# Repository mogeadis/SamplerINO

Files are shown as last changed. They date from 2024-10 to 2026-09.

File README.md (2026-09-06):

# SamplerINO 🔲

## Table of Contents

- [Description](#description)
    - [Project](#project)
    - [Repository](#repository)
    - [Technical Details](#technical-details)
- [Gallery](#gallery)
    - [Circuit Diagram](#circuit-diagram)
    - [3D Models](#3d-models)
    - [Hardware Assembly](#hardware-assembly)
    - [User Interface](#user-interface)
- [License](#license)

## Description

### Project
**SamplerINO** utilizes an *ATmega32U4* microcontroller and two *CAP1188* 8-channel capacitive touch sensor modules to assemble a USB MIDI controller featuring 16 touch-sensitive pads. The prototype circuit board is housed inside a custom-designed 3D printed enclosure, which facilitates the installation of the pads, as well as an LED indicator and a power switch. You can watch a video demonstration of this hardware MIDI controller and its dedicated software sampler at the following [link](https://youtu.be/IzE63Gio5Jo).

### Repository
The code in this repository is organized into several directories, with the source (`.cpp`) and header (`.h`) files of the controller located in the [*src*](src) and [*include*](include) directories, respectively. The *Max* patch implementing the user interface of the accompanying sampler, along with a collection of drum samples gathered from various royalty-free web sources, are contained in the [*max*](max) directory. Lastly, the 3D model (`.stl`) files are located in the [*3d*](3d) directory, while the [*img*](img) directory contains all images displayed in the present documentation.

### Technical Details
This project was developed using `Max 8.1.11` and *Visual Studio Code* on `Windows 10`, with the *PlatformIO* extension employed to upload the code to the *ATmega32U4* microcontroller embedded in an *Arduino*-compatible *Pro Micro* board. The controller pads were made by cutting 4×4cm pieces from a 0.5mm thick copper sheet, while the enclosure screw holes were designed for M2 threaded heat inserts. Lastly, a common anode RGB LED was used for the LED indicator, connected to 1KΩ resistors to prevent excessive current.

## Gallery

### Circuit Diagram
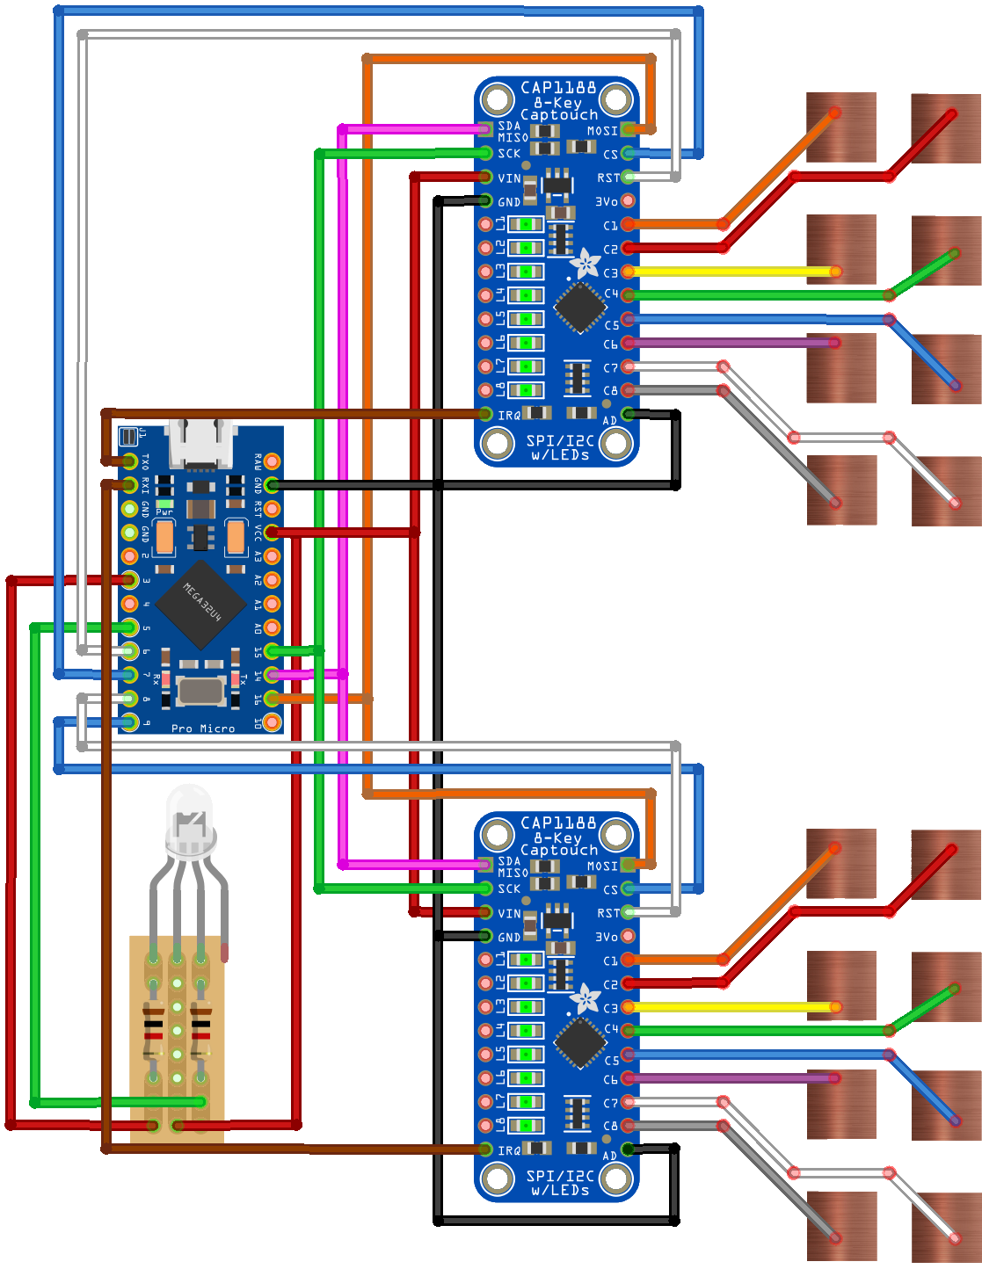
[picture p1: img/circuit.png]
Circuit Diagram


### 3D Models
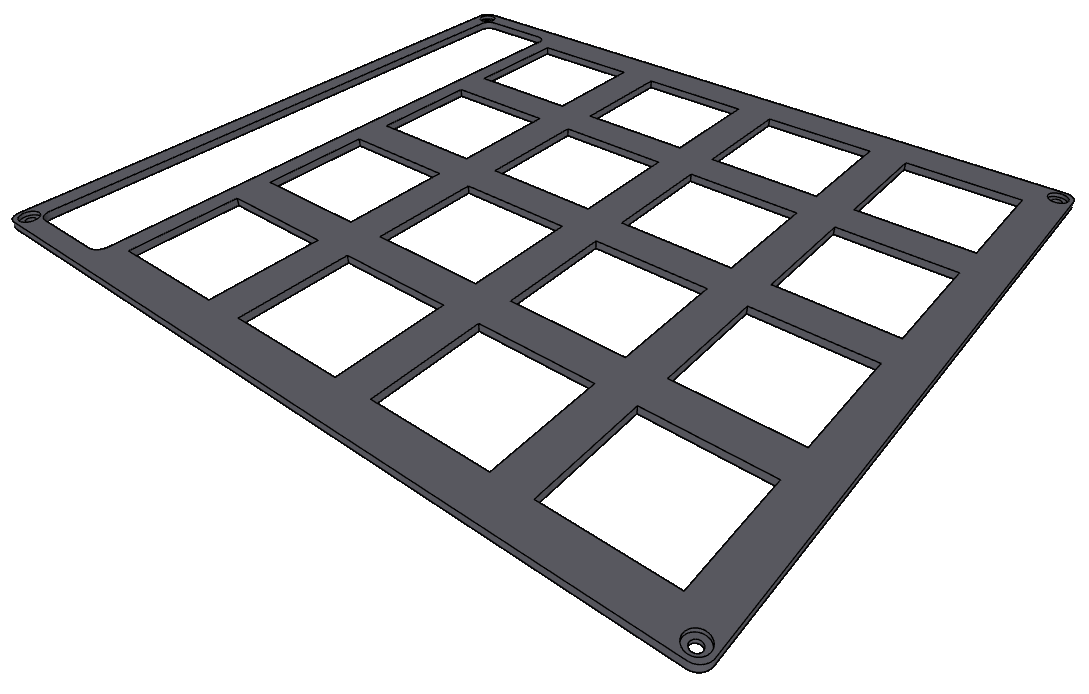
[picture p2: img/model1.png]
3D Model (Cover)

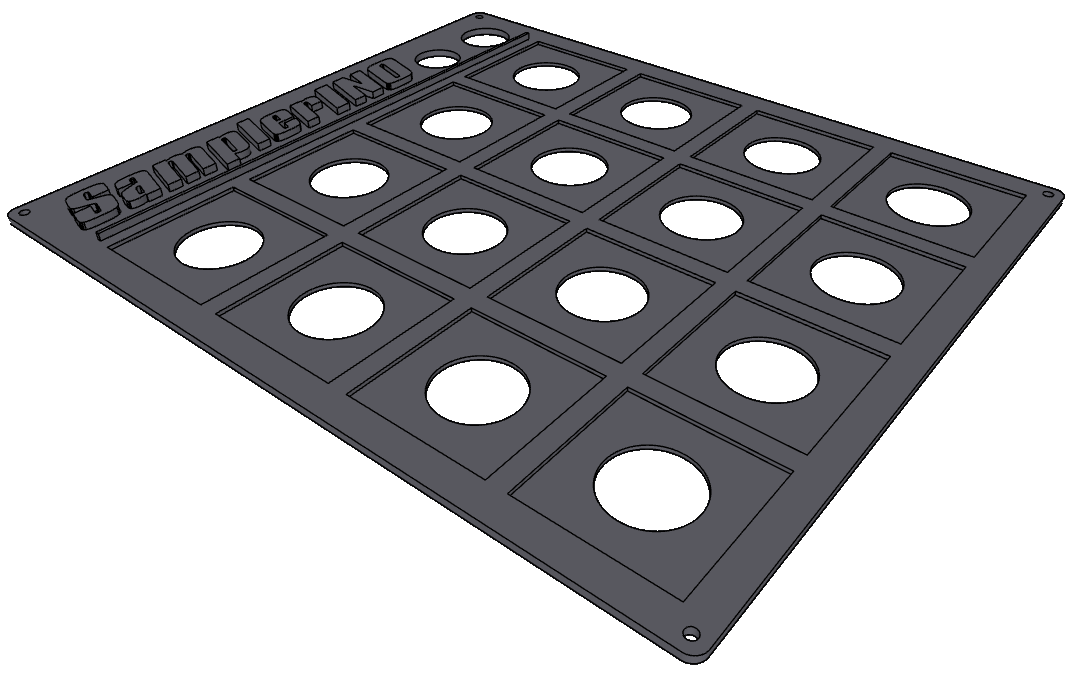
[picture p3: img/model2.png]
3D Model (Lid)

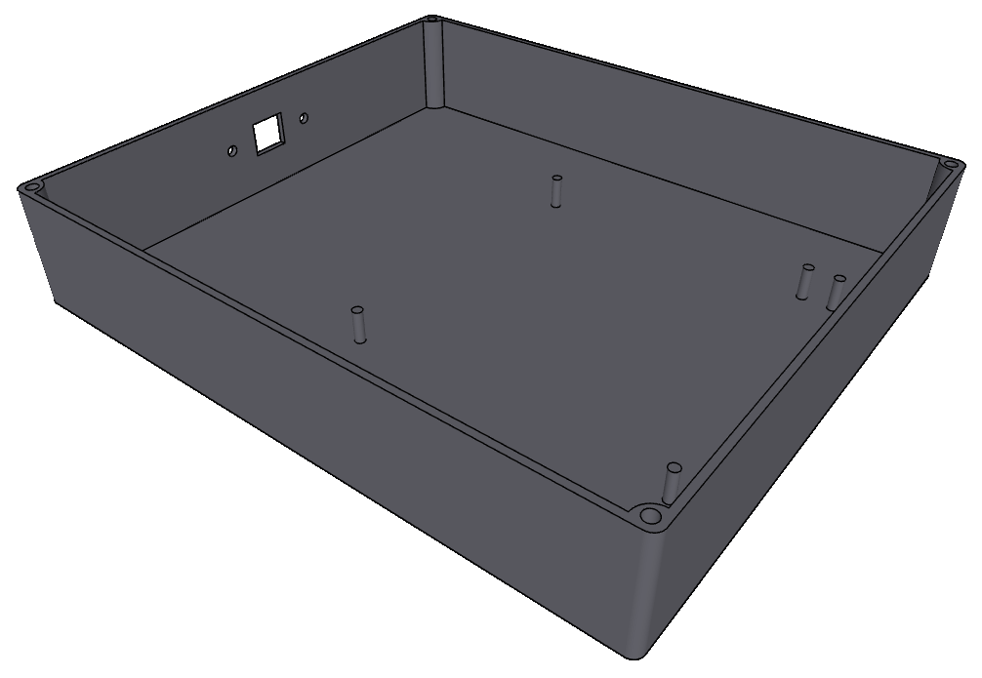
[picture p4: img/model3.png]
3D Model (Body)


### Hardware Assembly
Controller (#1)
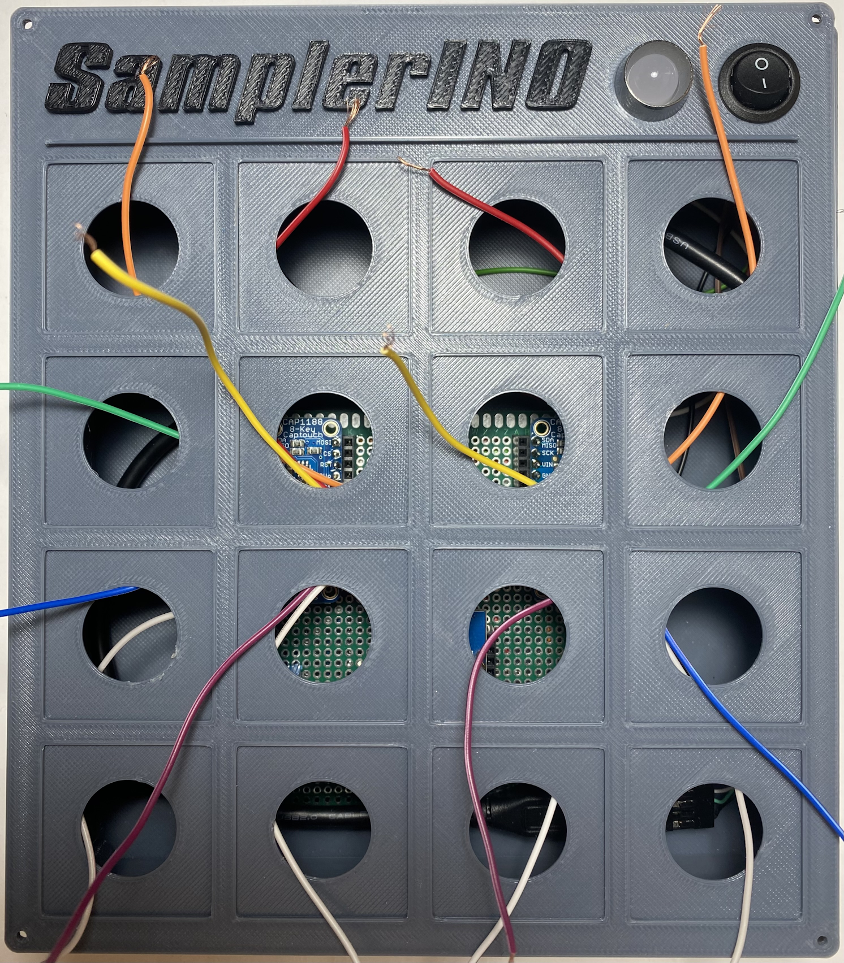
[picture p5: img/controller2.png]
Controller (#2)

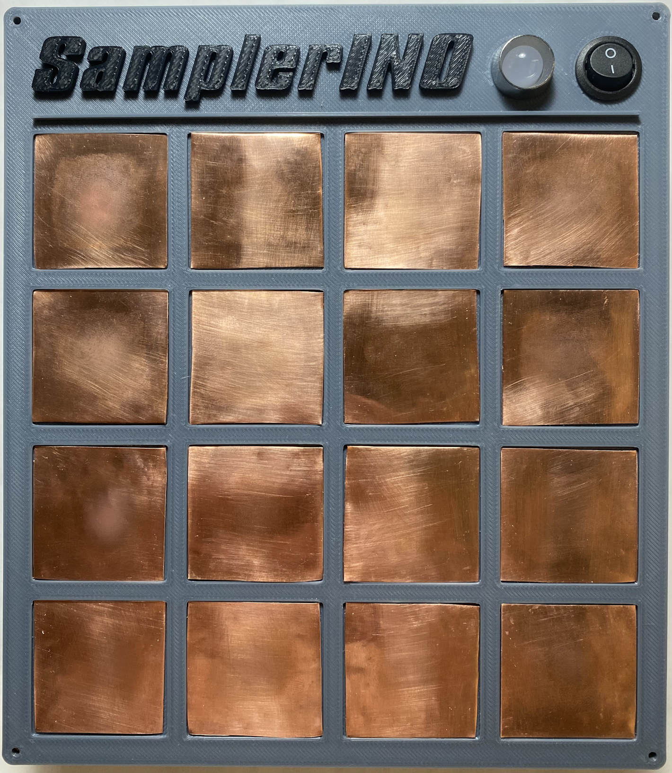
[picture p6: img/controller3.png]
Controller (#3)

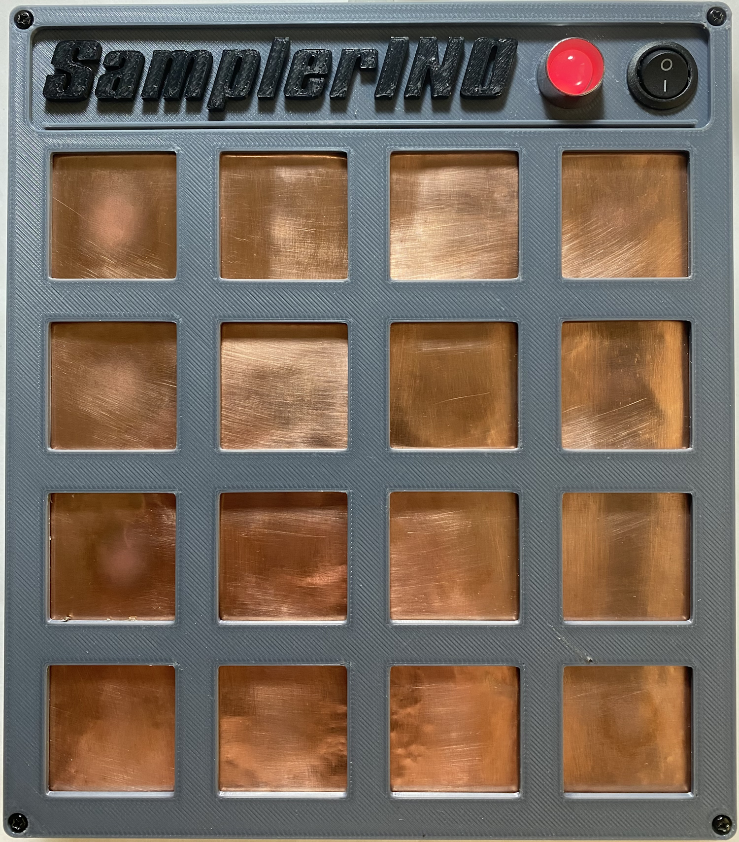
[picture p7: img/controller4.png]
Controller (#4)


### User Interface
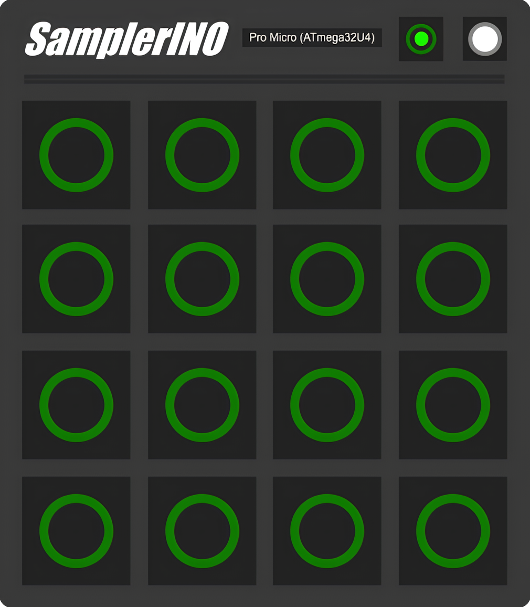
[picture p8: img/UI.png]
User Interface


## License

*SamplerINO* © *2024* by *Alexandros Iliadis* is licensed under the [GNU General Public License v3.0](https://choosealicense.com/licenses/gpl-3.0/).

Permissions of this strong copyleft license are conditioned on making available complete source code of licensed works and modifications, which include larger works using a licensed work, under the same license. Copyright and license notices must be preserved. Contributors provide an express grant of patent rights.

See the [`LICENSE.md`](LICENSE.md) file for more details.

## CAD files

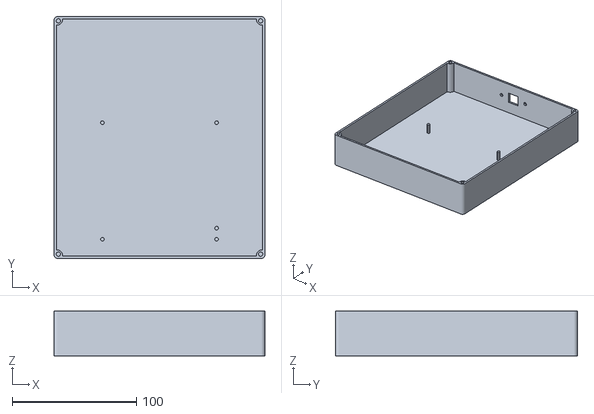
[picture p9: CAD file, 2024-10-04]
3d/model3.stl
170.0 x 195.0 x 36.0

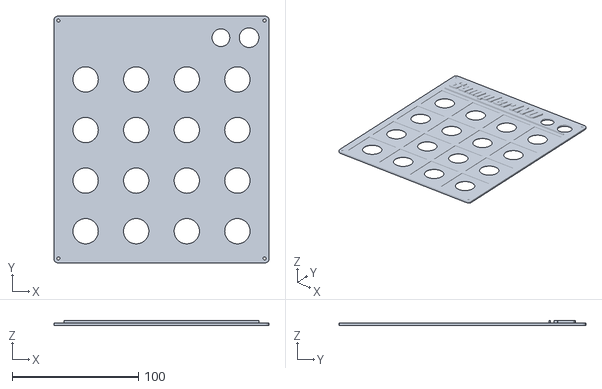
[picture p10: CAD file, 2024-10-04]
3d/model1.stl
170.0 x 195.0 x 4.00

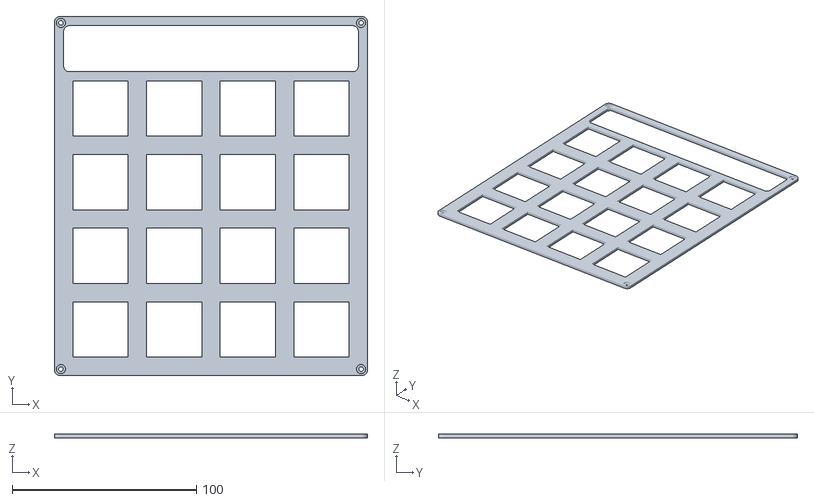
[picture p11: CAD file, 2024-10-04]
3d/model2.stl
170.0 x 195.0 x 2.00

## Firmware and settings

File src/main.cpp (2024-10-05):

/**************************************************************************************************
Filename: main.cpp

Description: This source file sets up the core functionality of the controller

Author: Alexandros Iliadis
Project: SamplerINO
Date: May 2024
**************************************************************************************************/

#include <Arduino.h>
#include "utilities.h"
#include "sensors.h"
#include "midi.h"

void setup()
{
	setupSerial();
	setupLED();
	setupModules();
}

void loop()
{
	if(interrupt)
	{
		registerNotes();
		sendData();
		interrupt = false;
	}
	controlLED();
}

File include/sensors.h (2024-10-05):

/**************************************************************************************************
Filename: sensors.h

Description: This header file sets up the touch sensors of the controller

Author: Alexandros Iliadis
Project: SamplerINO
Date: May 2024
**************************************************************************************************/

#ifndef SENSORS
#define SENSORS

// Include Libraries
#include <Arduino.h>
#include <Adafruit_CAP1188.h>

// Define Macros
#define NUM_OF_MODULES 2
#define SENSORS_PER_MODULE 8
#define NUM_OF_SENSORS NUM_OF_MODULES*SENSORS_PER_MODULE
#define MAIN_REGISTER 0x00
#define SENSORS_REGISTER 0x03
#define STANDBY_REGISTER 0x40
#define STANDBY_VALUE 0b11111111
#define REPEAT_RATE_REGISTER 0x28
#define REPEAT_RATE_VALUE 0b00000000
#define CALIBRATION_REGISTER 0x26
#define CALIBRATION_VALUE 0b11111111
#define RECALIBRATION_REGISTER 0x2F
#define RECALIBRATION_VALUE 0b10011111
#define CYCLE_REGISTER 0x24
#define CYCLE_VALUE 0b0001100
#define STANDBY_CYCLE_REGISTER 0x41
#define STANDBY_CYCLE_VALUE 0b0001100
#define SENSITIVITY_REGISTER 0x1F
#define SENSITIVITY_VALUE 0b1101111
#define STANDBY_SENSITIVITY_REGISTER 0x42
#define STANDBY_SENSITIVITY_VALUE 0b110

// Declare Variables
extern Adafruit_CAP1188 modules[NUM_OF_MODULES];
extern const byte cs_pins[NUM_OF_MODULES];
extern const byte rst_pins[NUM_OF_MODULES];
extern const byte irq_pins[NUM_OF_MODULES];
extern bool sensor_state[NUM_OF_SENSORS];
extern byte active_sensors;
extern volatile bool interrupt;

// Declare Functions
void setupModules();
void handleInterrupt();

#endif

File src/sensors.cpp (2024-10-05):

/**************************************************************************************************
Filename: sensors.cpp

Description: This source file defines the components declared in the corresponding header file

Author: Alexandros Iliadis
Project: SamplerINO
Date: May 2024
**************************************************************************************************/

#include "sensors.h"

// Define Variables
Adafruit_CAP1188 modules[NUM_OF_MODULES];
const byte cs_pins[NUM_OF_MODULES] = {9,7};
const byte rst_pins[NUM_OF_MODULES] = {8,6};
extern const byte irq_pins[NUM_OF_MODULES] = {1,0};
bool sensor_state[NUM_OF_SENSORS] = {0};
byte active_sensors = 0;
volatile bool interrupt = false;

// Define Functions
void setupModules()
{
    for(byte m = 0; m < NUM_OF_MODULES; m++)
    {
        modules[m] = Adafruit_CAP1188(cs_pins[m],rst_pins[m]);
        if(modules[m].begin())
        {
            pinMode(irq_pins[m],INPUT_PULLUP);
            attachInterrupt(digitalPinToInterrupt(irq_pins[m]),handleInterrupt,FALLING);
            modules[m].writeRegister(STANDBY_REGISTER,STANDBY_VALUE);
            modules[m].writeRegister(REPEAT_RATE_REGISTER,REPEAT_RATE_VALUE);
            modules[m].writeRegister(CALIBRATION_REGISTER,CALIBRATION_VALUE);
            modules[m].writeRegister(RECALIBRATION_REGISTER,RECALIBRATION_VALUE);
            modules[m].writeRegister(CYCLE_REGISTER,CYCLE_VALUE);
            modules[m].writeRegister(STANDBY_CYCLE_REGISTER,STANDBY_CYCLE_VALUE);
            modules[m].writeRegister(SENSITIVITY_REGISTER,SENSITIVITY_VALUE);
            modules[m].writeRegister(STANDBY_SENSITIVITY_REGISTER,STANDBY_SENSITIVITY_VALUE);
            Serial.print("CAP1188 Module #");
            Serial.println(m + 1);
            Serial.println("- Detection: Successful\n");
        }
        else
        {
            Serial.print("CAP1188 Module #");
            Serial.println(m + 1);
            Serial.println("- Detection: Failed\n");
            Serial.println("CHECK CONNECTIONS AND REBOOT SYSTEM TO PROCEED");
            while(true);
        }
    }
}

void handleInterrupt()
{
    interrupt = true;
}
